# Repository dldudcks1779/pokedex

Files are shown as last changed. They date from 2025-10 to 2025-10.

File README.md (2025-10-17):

# 포켓몬 트레이너 필수템! 포켓몬 도감 리뷰
<div align="center">
  <a href="https://www.youtube.com/watch?v=Ev5wCygICXk">
    YouTube
  </a>
</div>

---

## 1. Hardware Information
- **Main Board:** Raspberry Pi 3 Model B+
    - **CPU:** Broadcom BCM2837B0, Cortex-A53 (ARMv8) 64-bit SoC @ 1.4GHz
    - **RAM:** 1GB
- **Display:** MHS 3.2" TFT Touch Display
    - **Resolution:** 320x480
    - **Interface:** SPI
    - **Link:** [https://www.lcdwiki.com/MHS-3.2inch_Display](https://www.lcdwiki.com/MHS-3.2inch_Display)
- **Camera:** Raspberry Pi Camera Module V2 (8MP)
- **Audio**
    - **Speaker:** 3W 4Ω Speaker (Sensitivity 84 dB, Frequency Response 90 Hz - 20 kHz)
    - **Interface:** 3.5mm Jack on Raspberry Pi 3 B+
- **Storage:** 64GB microSD Card
- **Battery Fuel Gauge:** Gravity 3.7V Li Battery Fuel Gauge SKU DFR0563
    - **Link:** [https://wiki.dfrobot.com/gravity__3.7v_li_battery_fuel_gauge_sku__dfr0563](https://wiki.dfrobot.com/gravity__3.7v_li_battery_fuel_gauge_sku__dfr0563)
- **Battery Management IC:** IP5306 (Li-ion Charge/Boost Controller)
- **Circuit Diagram**<br>
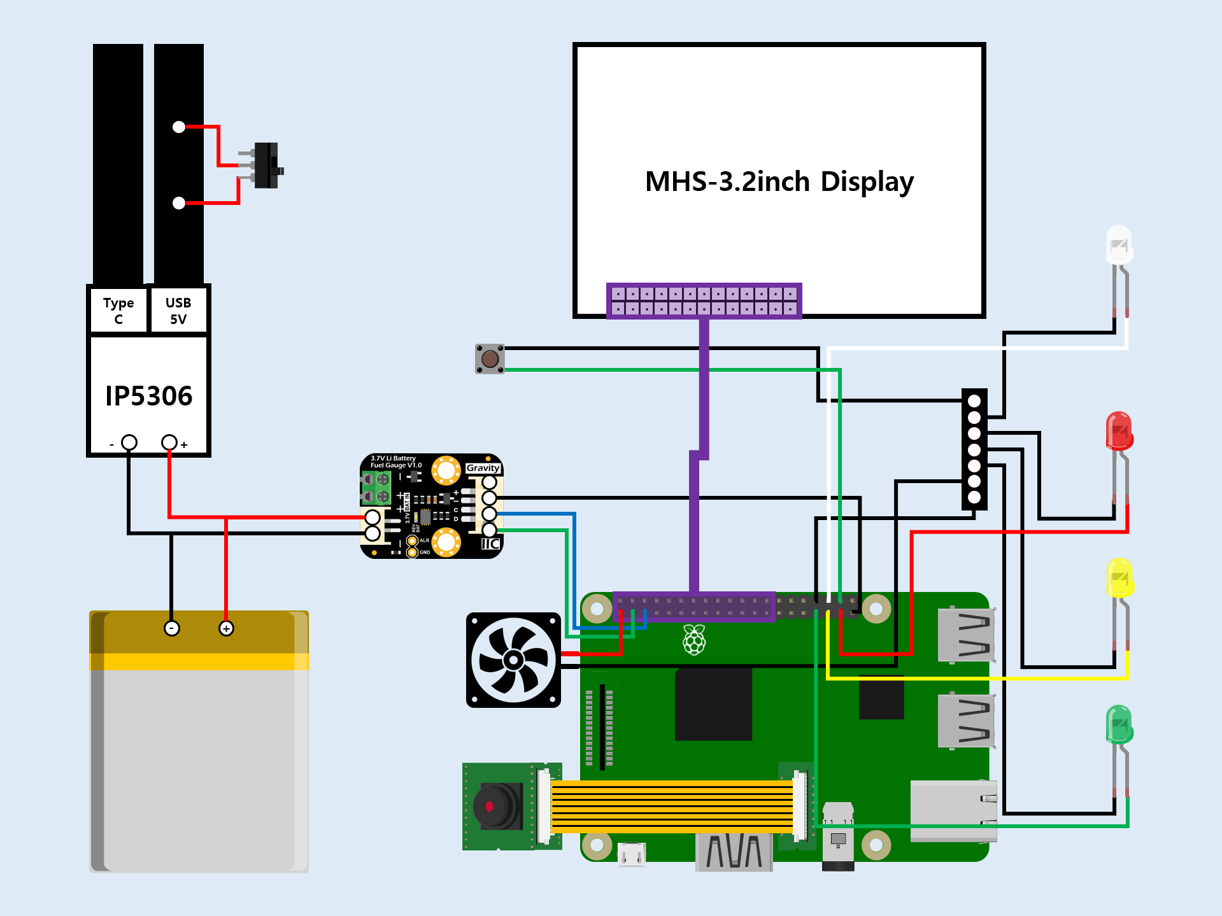
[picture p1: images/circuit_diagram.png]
Circuit Diagram
    

---

## 2. Software Information
- **Operating System:** Raspberry Pi OS with Desktop (32-bit)
    - **Debian Codename:** Bullseye (Version 11)
    - **Download Link:** [https://downloads.raspberrypi.org/raspios_armhf/images/raspios_armhf-2023-05-03/](https://downloads.raspberrypi.org/raspios_armhf/images/raspios_armhf-2023-05-03/)
- **Language & Libraries**
    - 
        -    
- **Machine Learning**
    - **Model**
        - **Type:** Image Classification
        - **Training Environment:** Teachable Machine by Google
            - **Link:** [https://teachablemachine.withgoogle.com](https://teachablemachine.withgoogle.com)
        - **Architecture:** MobileNetV2 (Transfer Learning)
        - **Framework:** TensorFlow Lite (TFLite)
    - **Hyperparameters**
        - **Epochs:** 50
        - **Batch Size:** 16
        - **Learning Rate:** 0.001
    - **Input/Output Details**
        - **Input Size:** 224x224
        - **Input Shape:** (1, 224, 224, 3)
        - **Output Shape:** (1, 9)
    - **Datasets**
        - **Number of Classes:** 9 classes
        - **Images per Class:** 50 images/class
        - **Total Images:** 450 images
        - **Data Split**
            - **Training Set:** 85%
            - **Validation Set:** 15%
        - **Path:** `datasets/`
    - **Confusion Matrix**        
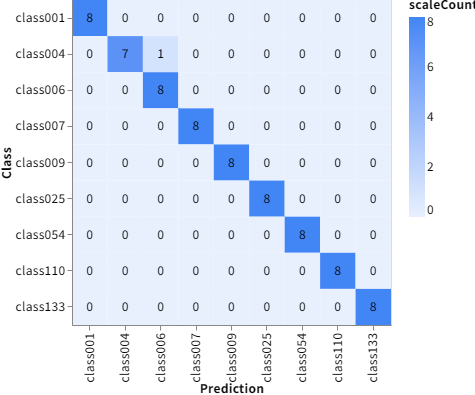
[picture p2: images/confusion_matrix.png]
Confusion Matrix
            
    - **Performance Metrics**
        - **Accuracy**<br>
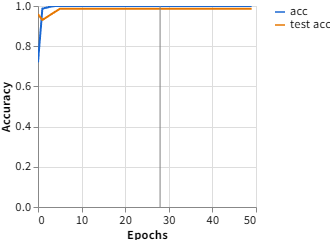
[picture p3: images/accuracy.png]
Accuracy
            
        - **Loss**<br>
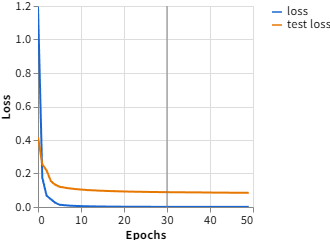
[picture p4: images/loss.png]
Loss
            
    - **Files Included**
        - **Model File:** `pokedex.tflite`
        - **Labels File:** `labels.txt`
##### ※ This content was created using the AI virtual actor service, Typecast. - Cast: Radio
- **Account Information**
    - **username:** `pokedex`
    - **password:** `0608`

---

## 3. Setup Instructions
### 1) System Update
- **Update Package List**
    ```bash
    sudo apt update
    ```
- **Upgrade Installed Packages**
    ```bash
    sudo apt upgrade -y
    ```

### 2) Raspberry Pi Configuration
- **Interfaces**    
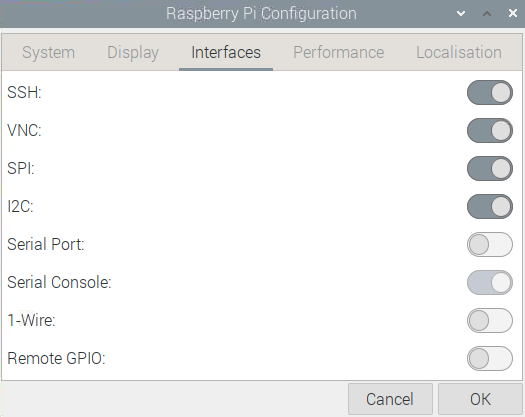
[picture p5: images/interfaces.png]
    
    - **SSH Enabled**
    - **VNC (Virtual Network Computing) Enabled**
    - **SPI (Serial Peripheral Interface) Enabled**
    - **I2C (Inter-Integrated Circuit) Enabled**

### 3) Display Settings (MHS 3.2" TFT Touch Display)
##### ※ Reference Link: [https://www.lcdwiki.com/MHS-3.2inch_Display](https://www.lcdwiki.com/MHS-3.2inch_Display)
#### 3.1) Install Display Driver
- **Clone the Driver Repository**
    ```bash
    git clone https://github.com/goodtft/LCD-show.git
    ```
- **Set Execution Permissions for the Directory**
    ```bash
    chmod -R 755 LCD-show
    ```
- **Navigate to the Driver Directory**
    ```bash
    cd LCD-show/
    ```
- **Install the Driver**
    ```bash
    sudo ./MHS32-show
    ```
#### 3.2) Rotate Screen Orientation
- **Navigate to the Driver Directory**
    ```bash
    cd LCD-show/
    ```
- **Execute 180° Rotation Script**
    ```bash
    sudo ./rotate.sh 180
    ```
#### ※ Restore HDMI Output
- **Navigate to the Driver Directory**
    ```bash
    cd LCD-show/
    ```
- **Execute HDMI Restoration Script**
    ```bash
    sudo ./LCD-hdmi
    ```

### 4) Install Libraries
#### 4.1) System Dependencies and Core Packages (APT)
- **Install Required Packages**
    ```bash
    sudo apt install -y libopenblas0 python3-opencv mpg123
    ```
    - **libopenblas0:** Optimized BLAS (Basic Linear Algebra Subprograms) library for high-performance numerical computing
    - **python3-opencv:** Library of programming functions primarily for real-time computer vision tasks
    - **mpg123:** Fast, console-based MPEG audio player and decoder
#### 4.2) Specific Python Modules (pip3)
- **Install Required Python Modules**
    ```bash
    sudo pip3 install smbus2==0.5.0 tflite-runtime==2.13.0 numpy==1.26.4
    ```
    - **smbus2:** Pure Python implementation for I2C protocol communication
    - **tflite-runtime:** Tools to run TensorFlow models efficiently on mobile, embedded, and IoT devices
    - **numpy:** Fundamental package for array computing and numerical operations with Python

### 5) Disable GUI (OSD) Warnings
#### 5.1) Edit Configuration File
- **Open the file using a text editor**
    ```bash
    sudo vi /boot/config.txt
    ```
    - **/boot/config.txt:** Configuration file for firmware-level hardware initialization and boot options
    - **Add Warning Suppression Option at the end of the file**
        ```diff
        + avoid_warnings=2
        ```
        - `avoid_warnings=1`: Hides the low voltage icon.
        - `avoid_warnings=2`: Hides the icon and all kernel messages.
#### 5.2) Apply Changes
- **Apply Changes by Rebooting**
    ```bash
     sudo reboot
    ```

### 6) Disable Sleep Mode and Hide Mouse Cursor
#### 6.1) Edit Configuration File
- **Open the file using a text editor**
    ```bash
    sudo vi /etc/lightdm/lightdm.conf
    ```
    - **/etc/lightdm/lightdm.conf:** Main configuration file for the LightDM display manager (manages graphical login sessions)
    - **Modify the xserver-command option in the [Seat:*] section (around line 95)**
        ```diff
        - #xserver-command=X
        + xserver-command=X -s 0 -dpms -nocursor
        ```
        - `-s 0`: Disables the screen saver
        - `-dpms`: Disables display power management features
        - `-nocursor`: Hides the mouse cursor
#### 6.2) Apply Changes
- **Apply Changes by Rebooting**
    ```bash
     sudo reboot
    ```

### 7) Auto-start Application on Boot
#### 7.1) Create Service File
- **Open the file using a text editor**
    ```bash
    sudo vi /etc/systemd/system/pokedex.service
    ```
    - **/etc/systemd/system/pokedex.service:** Systemd service file to configure the Pokedex application to start automatically on boot
    - **Add the following content**
        ```ini
        [Unit]
        Description=Pokedex Application
        Wants=graphical.target
        After=graphical.target
        
        [Service]
        User=pokedex
        Group=pokedex
        Type=simple
        WorkingDirectory=/home/pokedex
        Environment="DISPLAY=:0"
        Environment="XDG_RUNTIME_DIR=/run/user/1000"
        ExecStart=/usr/bin/python3 /home/pokedex/main.py
        Restart=on-failure
        RestartSec=5

        [Install]
        WantedBy=graphical.target
        ```
        - **[Unit] Section**
            - `Description`: Brief description of the service
            - `Wants`: Specifies the target that this service wants to be started with
            - `After`: Specifies the order in which units are started
        - **[Service] Section**
            - `User`: User to run the service as
            - `Group`: Group to run the service as
            - `Type`: Specifies the process start-up type
            - `WorkingDirectory`: Directory where the service will run
            - `Environment`: Sets environment variables for the service
            - `ExecStart`: Command to start the service
            - `Restart`: Defines the restart behavior on failure
            - `RestartSec`: Delay before restarting the service
        - **[Install] Section**
            - `WantedBy`: Specifies the target that this service should be started under
#### 7.2) Enable the Service
- **Reload Systemd Daemon**
    ```bash
    sudo systemctl daemon-reload
    ``` 
- **Enable the service to start on boot**
    ```bash
    sudo systemctl enable pokedex.service
    ```
- **Start the service immediately**
    ```bash
    sudo systemctl start pokedex.service
    ```
- **Check the status of the service**
    ```bash
    sudo systemctl status pokedex.service
    ```
#### 7.3) Apply Changes
- **Apply Changes by Rebooting**
    ```bash
     sudo reboot
    ```

---

## ※ Registered Pokemon
| CLASS | POKEMON | DESCRIPTION |
| :---: | :---: | :--- |
| `class001` | 이상해씨(Bulbasaur) | 태어나서 얼마 동안 등의 씨앗에 담긴 영양을 섭취하며 자란다. |
| `class004` | 파이리(Charmander) | 꼬리에서 타오르는 불꽃은 생명력의 상징. 기운이 없으면 불꽃이 약해진다. |
| `class006` | 리자몽(Charizard) | 정말 화가 난 리자몽의 꼬리 끝 불꽃은 푸르스름하게 불타오른다. |
| `class007` | 꼬부기(Squirtle) | 태어난 뒤 등이 부풀면서 단단한 등껍질이 생긴다. 입에서 강력한 거품을 발사한다. |
| `class009` | 거북왕(Blastoise) | 분사한 물의 기세에 밀리지 않도록 일부러 체중을 무겁게 불리고 있다. |
| `class025` | 피카츄(Pikachu) | 양 볼에는 전기를 저장하는 주머니가 있다. 화가 나면 저장한 전기를 단숨에 방출한다. |
| `class054` | 고라파덕(Psyduck) | 항상 두통에 시달리고 있다. 이 두통이 심해지면 이상한 힘을 쓰기 시작한다. |
| `class110` | 또도가스(Weezing) | 체내에 들어 있는 독가스의 농도를 극한까지 낮추면 최고급의 향수가 된다. |
| `class133` | 이브이(Eevee) | 환경 변화에 곧바로 적응할 수 있도록 여러 형태로 진화할 수 있는 가능성을 가지고 있다. |
- **Link:** [https://www.pokemonkorea.co.kr/pokedex](https://www.pokemonkorea.co.kr/pokedex)

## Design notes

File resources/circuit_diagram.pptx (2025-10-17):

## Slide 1

Type
C

USB 5V

MHS-3.2inch Display

IP5306

+

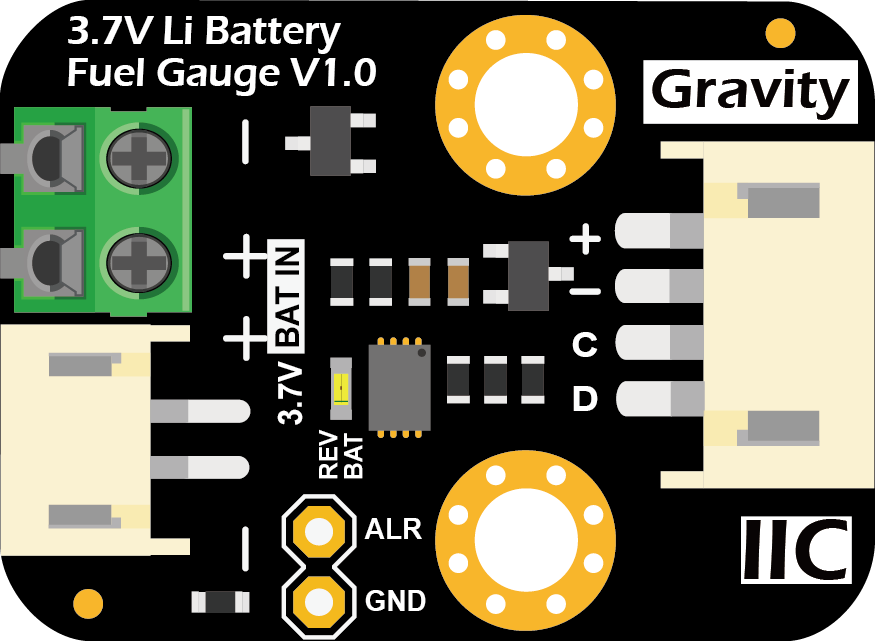
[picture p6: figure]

+

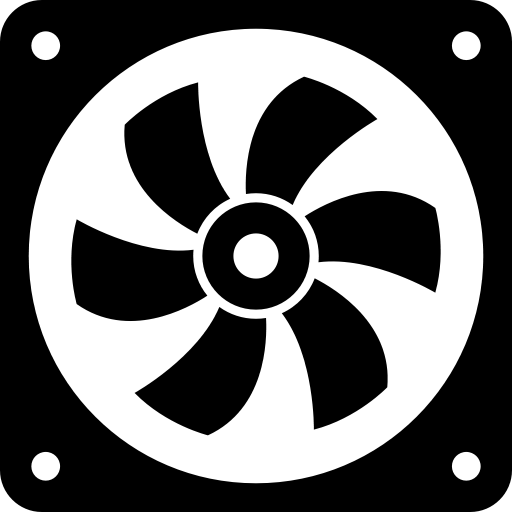
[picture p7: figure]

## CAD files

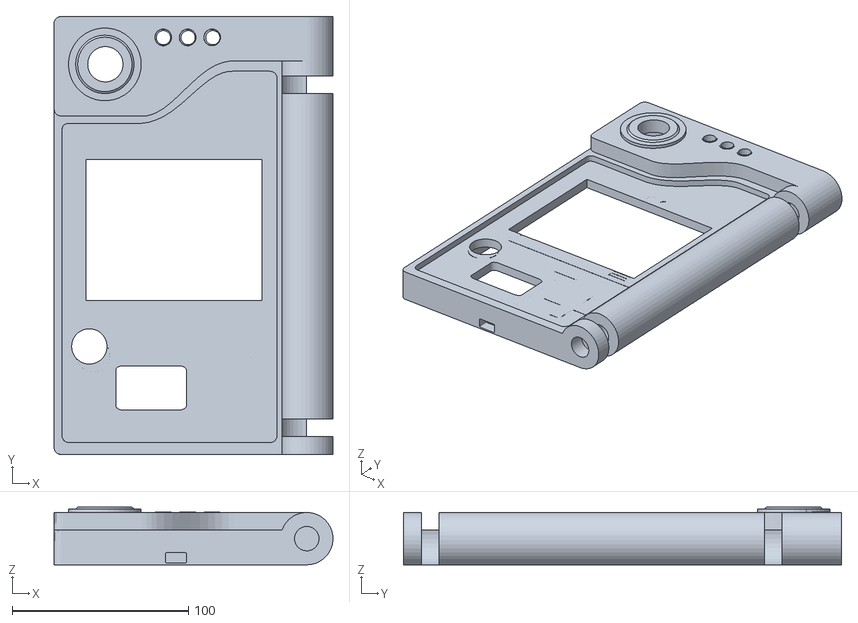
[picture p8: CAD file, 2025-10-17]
3D/Pokedex-TopBody.stl
158.1 x 248.2 x 32.7

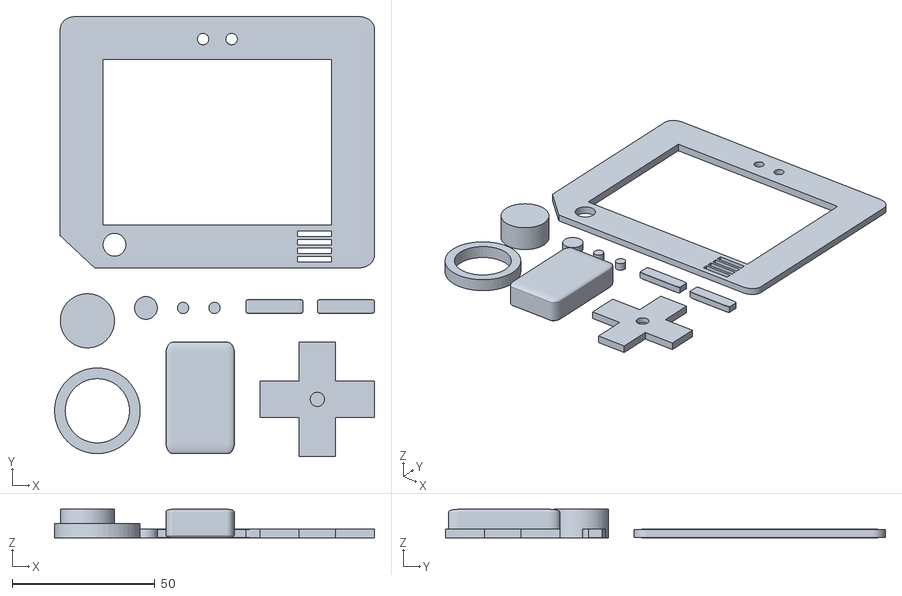
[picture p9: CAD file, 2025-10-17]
3D/Pokedex-BodyButton.stl
112.0 x 154.0 x 10.0

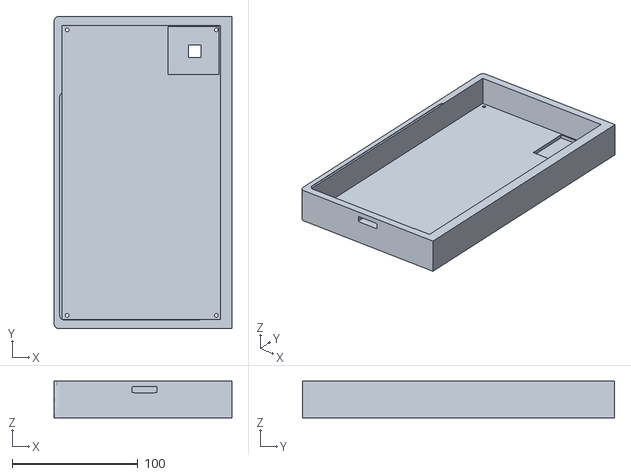
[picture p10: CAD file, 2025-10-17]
3D/Pokedex-BottomBody.stl
141.5 x 248.2 x 29.3

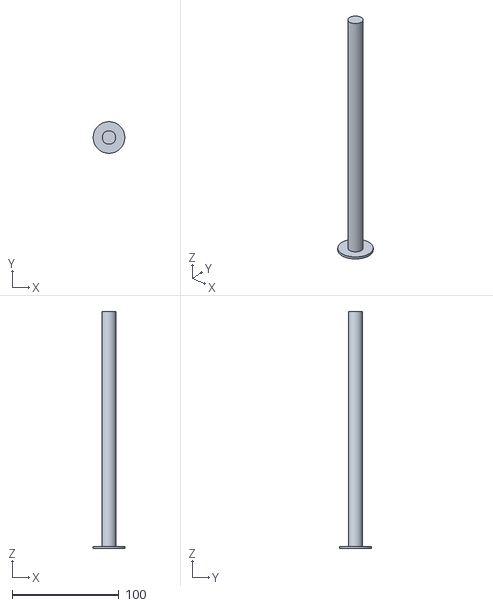
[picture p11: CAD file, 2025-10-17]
3D/Pokedex-Pin.stl
29.7 x 29.7 x 221.9

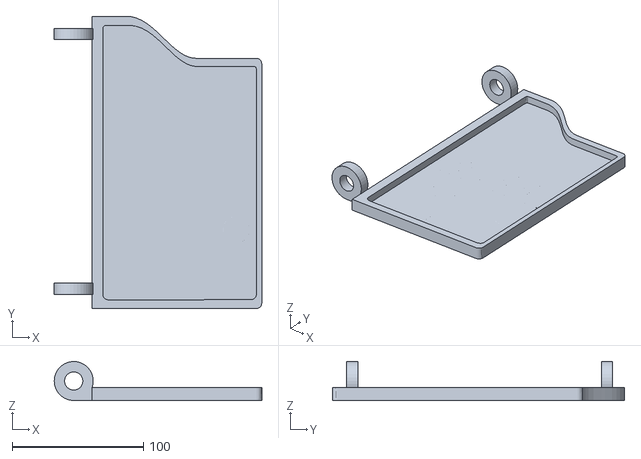
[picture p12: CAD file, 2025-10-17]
3D/Pokedex-Cover.stl
158.1 x 222.4 x 29.7

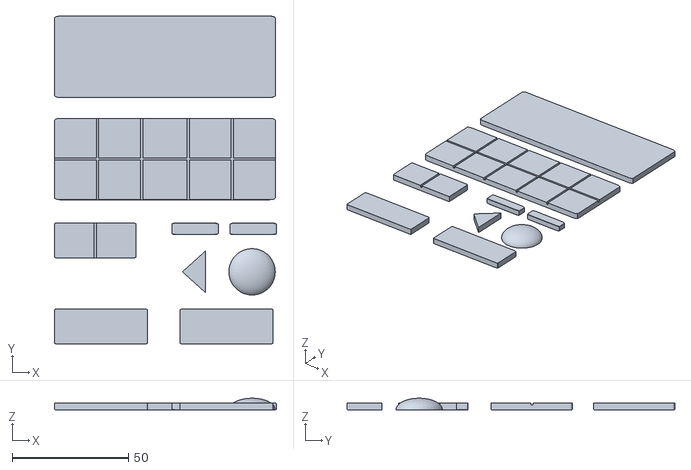
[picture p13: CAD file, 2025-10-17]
3D/Pokedex-CoverButton.stl
95.5 x 141.0 x 5.00

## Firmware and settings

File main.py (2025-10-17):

import time
import cv2
import RPi.GPIO as GPIO
import config
import camera
import battery
import audio_player
from tflite_model import TFLiteModel

# 전역 변수 초기화
button_pressed = False         # 버튼 눌림 상태
last_play_led_blink_time = 0.0 # 재생 상태 LED 깜빡임 마지막 시간
last_battery_check_time = 0.0  # 배터리 잔량 마지막 측정 시간
playing = False                # 오디오 재생 상태
paused = False                 # 오디오 일시정지 상태
last_audio_process = None      # 마지막 오디오 재생 프로세스
last_playback_end_time = 0.0   # 마지막 오디오 재생 종료 시간
last_cropped_frame = None      # 마지막 크롭된 프레임 (TFLite 모델 추론)
last_display_frame = None      # 마지막 디스플레이 프레임 (화면 출력)

# 버튼 눌림 감지 버튼 콜백 함수
def on_button_press(_):
    global button_pressed
    button_pressed = True

# GPIO 초기화 및 설정
def init_gpio():
    GPIO.setmode(GPIO.BCM)
    for pin in (config.BATTERY_GREEN_LED_PIN, config.BATTERY_YELLOW_LED_PIN, config.BATTERY_RED_LED_PIN):
        GPIO.setup(pin, GPIO.OUT, initial=GPIO.LOW)
    GPIO.setup(config.PLAY_LED_PIN, GPIO.OUT, initial=GPIO.LOW)
    GPIO.setup(config.BUTTON_PIN, GPIO.IN, pull_up_down=GPIO.PUD_UP)
    GPIO.add_event_detect(config.BUTTON_PIN, GPIO.FALLING, callback=on_button_press, bouncetime=200)

# 배터리 잔량 LED 설정
def set_battery_led(green=False, yellow=False, red=False):
    GPIO.output(config.BATTERY_GREEN_LED_PIN, GPIO.HIGH if green else GPIO.LOW)
    GPIO.output(config.BATTERY_YELLOW_LED_PIN, GPIO.HIGH if yellow else GPIO.LOW)
    GPIO.output(config.BATTERY_RED_LED_PIN, GPIO.HIGH if red else GPIO.LOW)

# 재생 상태 LED 설정
def set_play_led(play: bool):
    GPIO.output(config.PLAY_LED_PIN, GPIO.HIGH if play else GPIO.LOW)

# 재생 상태 LED 토글
def toggle_play_led():
    GPIO.output(config.PLAY_LED_PIN, not GPIO.input(config.PLAY_LED_PIN))

# 재생 상태 LED 깜빡임 업데이트
def update_play_led_blink(last_time, blink_interval=0.1):
    now = time.time()
    if (now - last_time) >= blink_interval:
        toggle_play_led()
        return now
    return last_time

# 모든 LED 끄기
def cleanup_led():
    set_battery_led(False, False, False)
    set_play_led(False)

# 리소스(카메라, OpenCV, I2C, GPIO 등) 해제 및 정리
def cleanup_resources(cap, smbus):
    try:
        if cap:
            cap.release()
        cv2.destroyAllWindows()
    except Exception as exception:
        print(f"ERROR: 카메라 및 OpenCV 리소스 해제 실패 - {exception}")
    try:
        if smbus:
            smbus.close()
    except Exception as exception:
        print(f"ERROR: I2C SMBus 연결 종료 실패 - {exception}")
    try:
        cleanup_led()
        GPIO.cleanup()
    except Exception as exception:
        print(f"ERROR: LED 및 GPIO 리소스 정리 실패 - {exception}")
    
# 배터리 잔량 측정 핸들러
def handle_battery(smbus):
    global last_battery_check_time
    now = time.time()
    if (now - last_battery_check_time) < config.BATTERY_CHECK_INTERVAL_SECONDS:
        return
    last_battery_check_time = now
    soc = battery.get_battery_soc(smbus)
    print(f"배터리 잔량: {soc}%")
    if soc > config.BATTERY_THRESHOLD_HIGH:
        set_battery_led(green=True)
    elif soc > config.BATTERY_THRESHOLD_LOW:
        set_battery_led(yellow=True)
    else:
        set_battery_led(red=True)

# 오디오 핸들러
def handle_audio():
    global playing, paused, last_audio_process, last_playback_end_time
    if not playing:
        return
    if last_audio_process and last_audio_process.poll() is not None:
        playing = False
        paused = False
        set_play_led(False)
        last_audio_process = None
        last_playback_end_time = time.time()

# TFLite 모델 추론
def inference(model: TFLiteModel, frame):
    label, probability = model.run_inference(frame)
    return label, probability

# 오디오 재생
def play_audio(label: str):
    global playing, last_audio_process
    mp3_file_path = audio_player.find_mp3_file(label)
    popen = audio_player.play_mp3_file(mp3_file_path)
    if popen:
        playing = True
        last_audio_process = popen

# 버튼 핸들러
def handle_button(model: TFLiteModel):
    global button_pressed, playing, paused, last_cropped_frame
    if not button_pressed:
        return
    button_pressed = False
    if playing or last_cropped_frame is None:
        return
    label, probability = model.run_inference(last_cropped_frame)
    print(f"추론 결과: {label} (정확도: {probability:.2f})")
    play_audio(label)
    paused = True

if __name__ == "__main__":
    init_gpio()
    cap = camera.create_video_capture()
    camera.setup_fullscreen_window(config.WINDOW_NAME)
    smbus = battery.init_smbus()
    model = TFLiteModel(config.LABELS_PATH, config.MODEL_PATH)
    try:
        while True:
            handle_battery(smbus)
            handle_audio()
            if playing:
                last_play_led_blink_time = update_play_led_blink(last_play_led_blink_time)
            elif GPIO.input(config.PLAY_LED_PIN) == GPIO.HIGH:
                set_play_led(False)
            if not paused:
                ret, frame = cap.read()
                if not ret:
                    print("프레임 읽기 실패")
                    break
                display_frame = cv2.resize(frame, (480, 360), interpolation=cv2.INTER_LINEAR)
                height, width = display_frame.shape[:2]
                crop_size = min(height, width)
                x1 = (width - crop_size) // 2
                y1 = (height - crop_size) // 2
                cropped_image = display_frame[y1:y1+crop_size, x1:x1+crop_size]
                last_cropped_frame = cv2.resize(cropped_image, (config.INPUT_WIDTH, config.INPUT_WIDTH), interpolation=cv2.INTER_LINEAR)
                last_display_frame = display_frame
            if last_display_frame is not None:
                cv2.imshow(config.WINDOW_NAME, last_display_frame)
            handle_button(model)
            if cv2.waitKey(1) == 27:
                break
    except Exception as exception:
        print(f"{exception}")
    finally:
        print("프로그램 종료")
        cleanup_resources(cap, smbus)

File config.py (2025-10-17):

# GStreamer를 이용한 카메라 데이터 처리 파이프라인 정의
GSTREAMER_PIPELINE = (
    "libcamerasrc "                                      # libcamera 라이브러리를 통해 카메라 하드웨어에서 영상 데이터 수집
    "! video/x-raw,width=480,height=360,framerate=30/1 " # 카메라에서 나오는 영상의 속성을 설정: 압축되지 않은 원본(raw) 비디오를 가로 480, 세로 360 픽셀 크기와 초당 30프레임으로 지정
    "! videoconvert ! video/x-raw,format=BGR "           # 영상 데이터의 색상 형식을 변환: OpenCV 라이브러리에서 표준으로 사용하는 색상 순서인 BGR 형식으로 변환
    "! videoscale "                                      # 영상 데이터의 크기를 조절: 다른 요소들 간의 데이터 형식 호환성을 보장하고 파이프라인의 안정성을 높임
    "! appsink drop=1 max-buffers=1 sync=false"          # 처리된 영상을 현재 실행 중인 파이썬 애플리케이션으로 전달: 처리가 늦어질 경우 오래된 프레임을 버리고 가능한 한 가장 최신 프레임을 빠르게 전달하여 실시간 성능을 극대화
)

# 창 이름
WINDOW_NAME = "POKEDEX WINDOW"

# GPIO 핀 번호 (BCM)
BATTERY_GREEN_LED_PIN = 13  # 초록색 LED (배터리 70% 이상)
BATTERY_YELLOW_LED_PIN = 19 # 노란색 LED (배터리 30% 이상)
BATTERY_RED_LED_PIN = 26    # 빨간색 LED (배터리 0% 이상)
PLAY_LED_PIN = 16           # 재생 상태 LED
BUTTON_PIN = 20             # 버튼

# 배터리 임계값 (%)
BATTERY_THRESHOLD_HIGH = 70.0 # 배터리 잔량 높은 기준
BATTERY_THRESHOLD_LOW = 30.0  # 배터리 잔량 낮은 기준

# I2C 통신 설정 (MAX17043 배터리 잔량 측정 IC)
MAX17043_I2C_ADDRESS = 0x36  # MAX17043 칩의 I2C 장치 주소
MAX17043_SOC_REGISTER = 0x04 # 칩 내부의 배터리 잔량(SOC) 값이 저장된 레지스터 주소

# 배터리 체크 주기 (초)
BATTERY_CHECK_INTERVAL_SECONDS = 5.0

# Teachable Machine TFLite 모델 설정
MODEL_PATH = "pokedex.tflite"         # TFLite 모델 경로
LABELS_PATH = "labels.txt"            # 라벨 파일 경로
INPUT_HEIGHT, INPUT_WIDTH = 224, 224  # 모델 입력 이미지 크기 (높이, 너비)

# 사운드 파일(.mp3) 디렉터리 경로
SOUNDS_DIRECTORY = "./sounds"
